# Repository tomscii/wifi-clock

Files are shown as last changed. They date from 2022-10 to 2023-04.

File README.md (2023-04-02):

## NTP-synced clock and SNMP sensors over WiFi with Raspberry Pico W

(https://tomscii.sig7.se/images/wifi-clock/wifi-clock.jpg)

Details: https://tomscii.sig7.se/wifi-clock

### Project organisation

- `doc` - documentation, design notes
- `hw` - hardware design (KiCAD)
- `pico_w` - software (Pico W)

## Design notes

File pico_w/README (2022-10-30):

To build:

mkdir build && cd build
cmake -DPICO_BOARD=pico_w -DWIFI_SSID="Your Network" -DWIFI_PASSWORD="Your Password" ..
make

To upload to RPi Pico W board
(connected via USB, powered up with BOOTSEL pressed):

sudo mount /dev/sda1 /mnt/pico
sudo cp wifi_clock.uf2 /mnt/pico/
sync && sudo umount /mnt/pico

To connect using hardware UART
(PicoW pin 1 = UART0_TX, pin 2 = UART0_RX, pin 3 = GND):
minicom -D /dev/ttyUSB0 -b 115200

To connect using USB CDC:
minicom -D /dev/ttyACM0 -b 115200

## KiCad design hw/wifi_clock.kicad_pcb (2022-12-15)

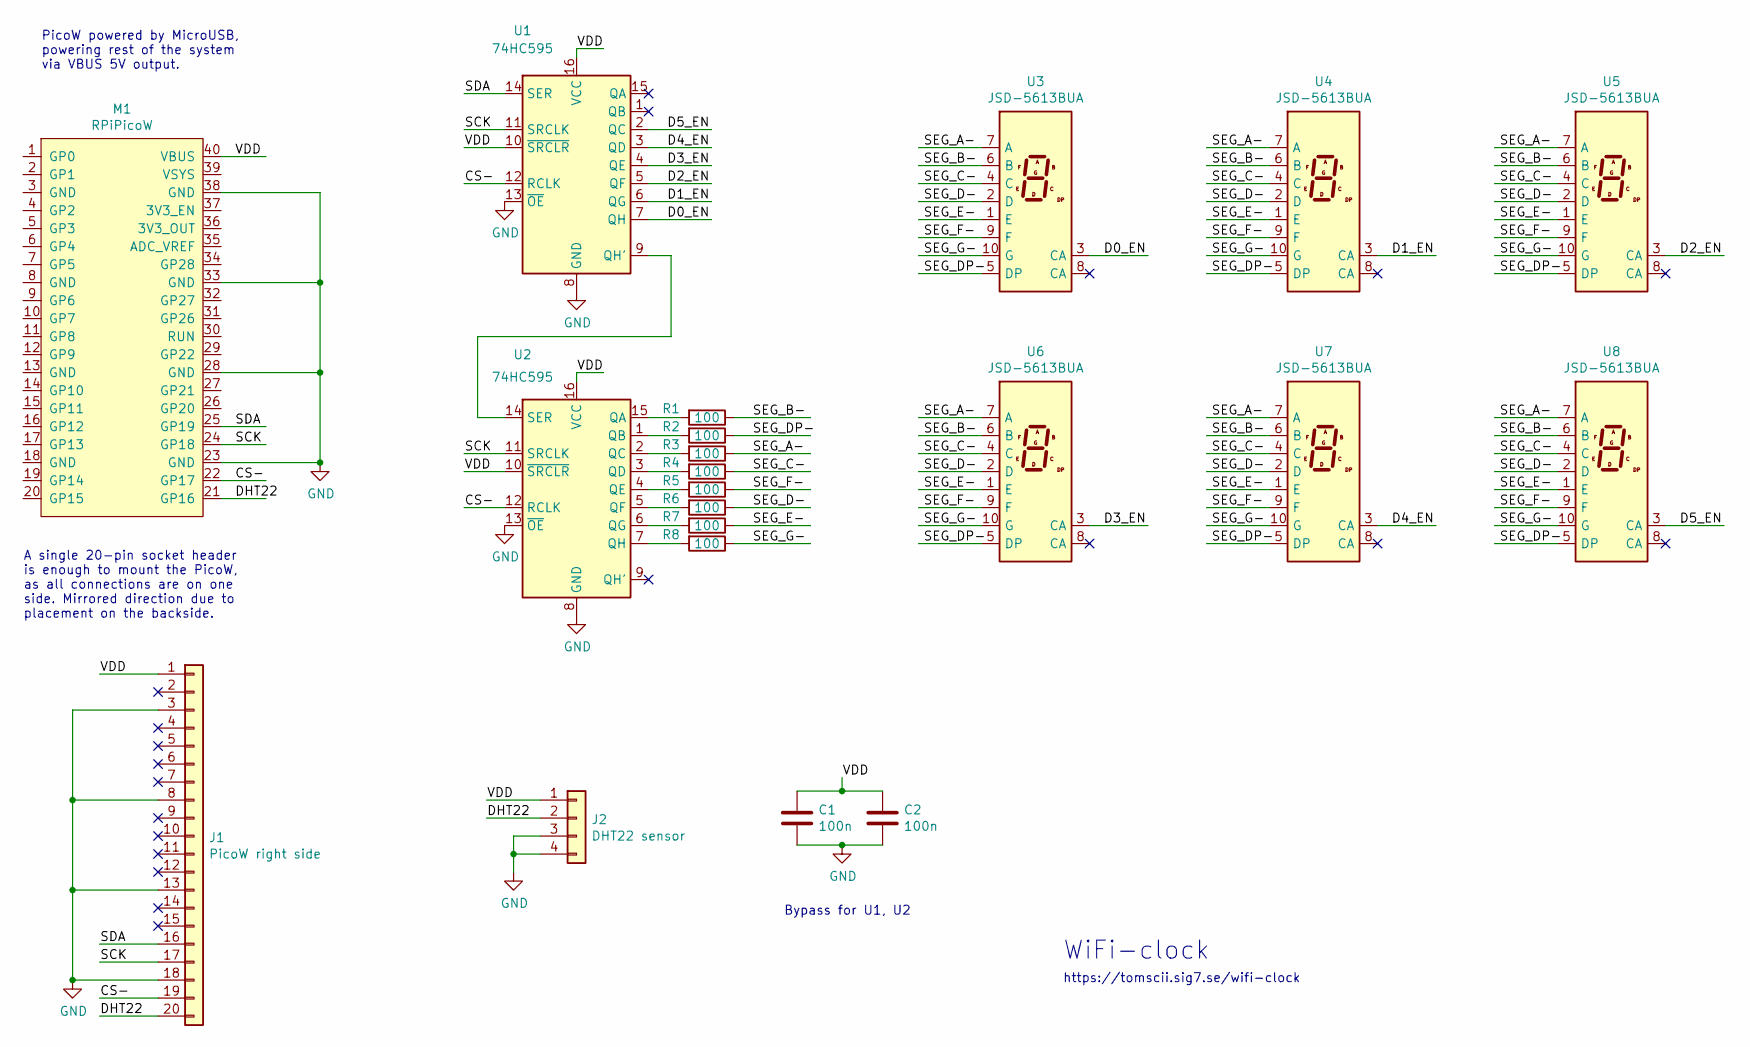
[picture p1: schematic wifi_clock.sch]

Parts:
C1, C2: 100n; C_Rect_L7.2mm_W2.5mm_P5.00mm_FKS2_FKP2_MKS2_MKP2
J1: PicoW right side; PinSocket_1x20_P2.54mm_Vertical
J2: DHT22 sensor; PinSocket_1x04_P2.54mm_Vertical
M1: RPiPicoW
R1, R2, R3, R4, R5, R6, R7, R8: 100; R_Axial_DIN0204_L3.6mm_D1.6mm_P7.62mm_Horizontal
U1, U2: 74HC595; DIP-16_W7.62mm
U3, U4, U5, U6, U7, U8: JSD-5613BUA; 7SegmentLED_LTS6760_LTS6780

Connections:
/CS-: J1.19, M1.22 (GP17), U1.12 (RCLK), U2.12 (RCLK)
/D0_EN: U1.7 (QH), U3.3 (CA)
/D1_EN: U1.6 (QG), U4.3 (CA)
/D2_EN: U1.5 (QF), U5.3 (CA)
/D3_EN: U1.4 (QE), U6.3 (CA)
/D4_EN: U1.3 (QD), U7.3 (CA)
/D5_EN: U1.2 (QC), U8.3 (CA)
/DHT22: J1.20, J2.2, M1.21 (GP16)
/SCK: J1.17, M1.24 (GP18), U1.11 (SRCLK), U2.11 (SRCLK)
/SDA: J1.16, M1.25 (GP19), U1.14 (SER)
/SEG_A-: R3.1, U3.7 (A), U4.7 (A), U5.7 (A), U6.7 (A), U7.7 (A), U8.7 (A)
/SEG_B-: R1.1, U3.6 (B), U4.6 (B), U5.6 (B), U6.6 (B), U7.6 (B), U8.6 (B)
/SEG_C-: R4.1, U3.4 (C), U4.4 (C), U5.4 (C), U6.4 (C), U7.4 (C), U8.4 (C)
/SEG_D-: R6.1, U3.2 (D), U4.2 (D), U5.2 (D), U6.2 (D), U7.2 (D), U8.2 (D)
/SEG_DP-: R2.1, U3.5 (DP), U4.5 (DP), U5.5 (DP), U6.5 (DP), U7.5 (DP), U8.5 (DP)
/SEG_E-: R7.1, U3.1 (E), U4.1 (E), U5.1 (E), U6.1 (E), U7.1 (E), U8.1 (E)
/SEG_F-: R5.1, U3.9 (F), U4.9 (F), U5.9 (F), U6.9 (F), U7.9 (F), U8.9 (F)
/SEG_G-: R8.1, U3.10 (G), U4.10 (G), U5.10 (G), U6.10 (G), U7.10 (G), U8.10 (G)
/VDD: C1.1, C2.1, J1.1, J2.1, M1.40 (VBUS), U1.10 (~SRCLR), U1.16 (VCC), U2.10 (~SRCLR), U2.16 (VCC)
GND: C1.2, C2.2, J1.3, J1.8, J1.13, J1.18, J2.3, J2.4, M1.23 (GND), M1.28 (GND), M1.33 (GND), M1.38 (GND), U1.8 (GND), U1.13 (~OE), U2.8 (GND), U2.13 (~OE)
unnamed: R1.2, U2.15 (QA)
unnamed: R2.2, U2.1 (QB)
unnamed: R3.2, U2.2 (QC)
unnamed: R4.2, U2.3 (QD)
unnamed: R5.2, U2.4 (QE)
unnamed: R6.2, U2.5 (QF)
unnamed: R7.2, U2.6 (QG)
unnamed: R8.2, U2.7 (QH)
unnamed: U1.9 (QH'), U2.14 (SER)

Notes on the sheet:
PicoW powered by MicroUSB, powering rest of the system via VBUS 5V output.
A single 20-pin socket header is enough to mount the PicoW, as all connections are on one side. Mirrored direction due to placement on the backside.
WiFi-clock
https://tomscii.sig7.se/wifi-clock
Bypass for U1, U2

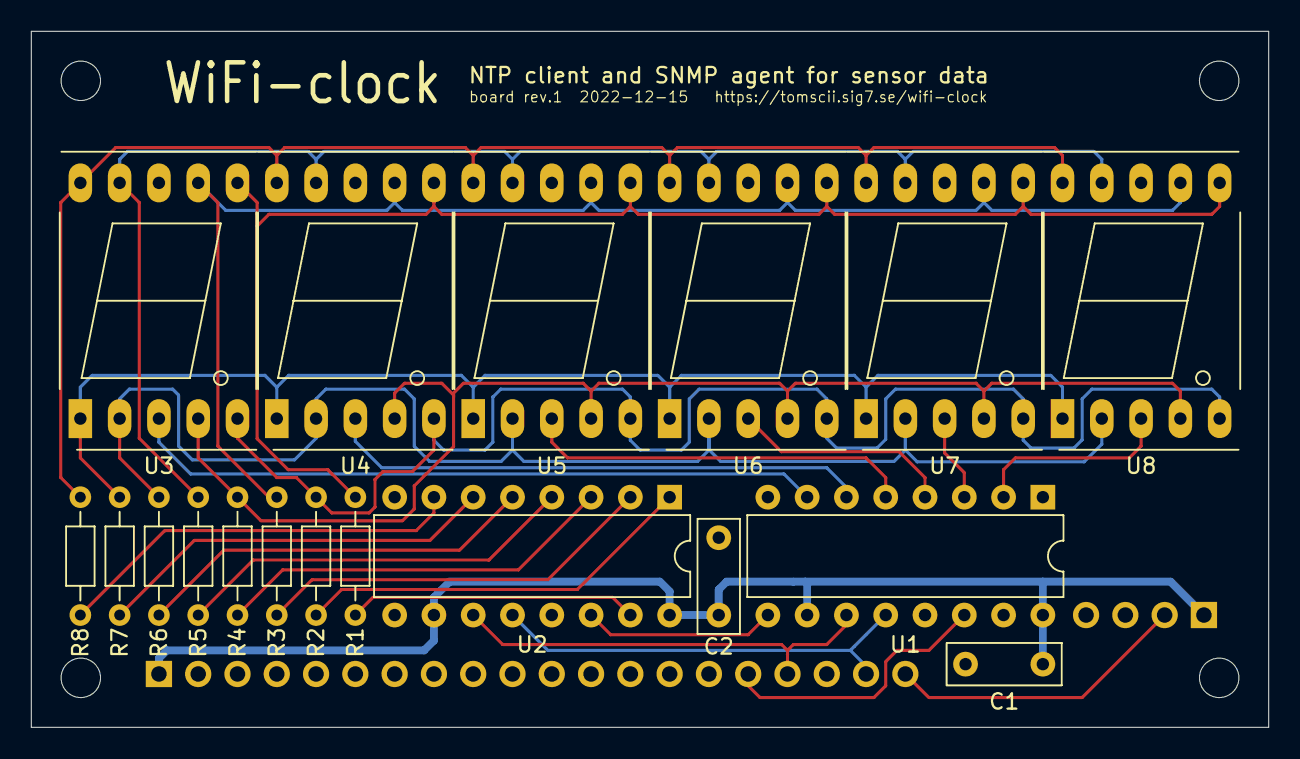
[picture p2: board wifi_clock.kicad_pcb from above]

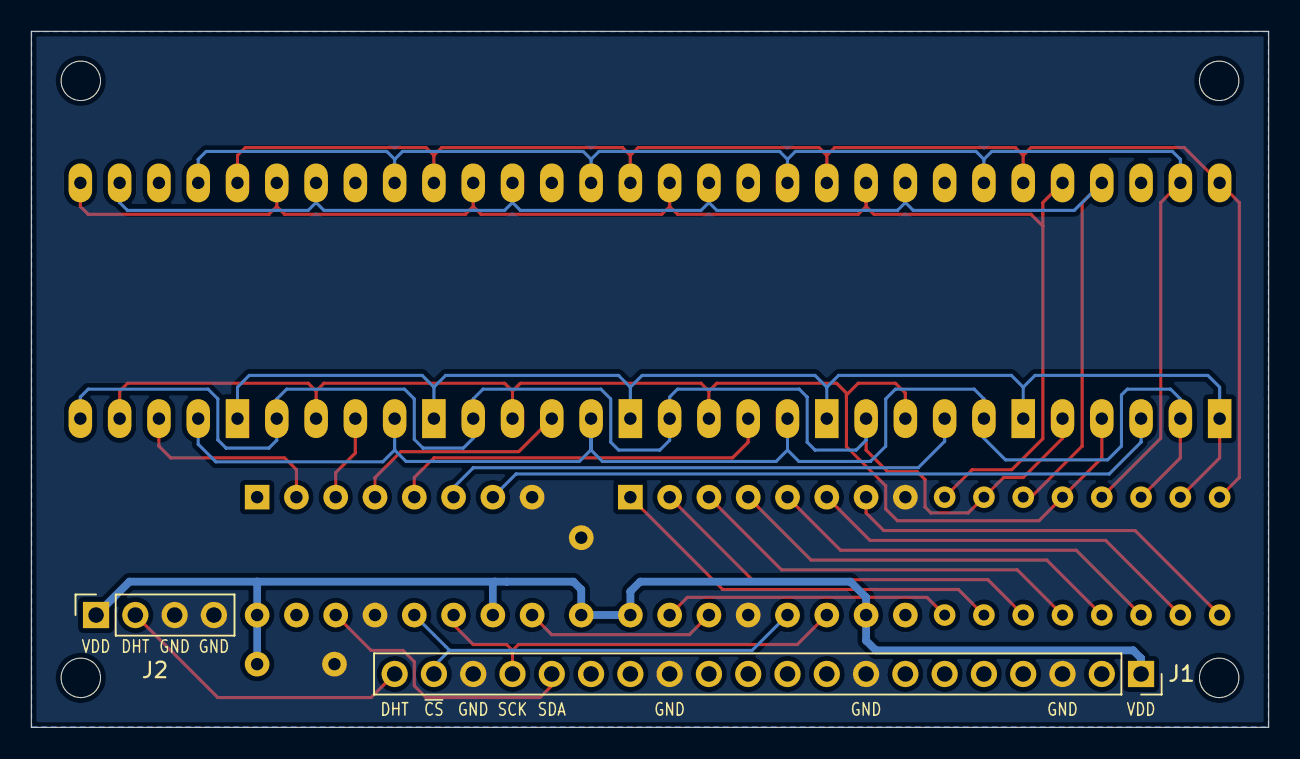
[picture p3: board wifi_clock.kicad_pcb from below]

Board: 2 copper layers, 80.0 x 45.0 mm, 20 parts (2 on the bottom side), 29 nets.

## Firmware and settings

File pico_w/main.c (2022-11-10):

#include "dht.h"
#include "display.h"
#include "ntp.h"
#include "snmp.h"
#include "wifi.h"

#include "pico/stdlib.h"
#include "pico/cyw43_arch.h"
#include "pico/util/datetime.h"

#include "hardware/rtc.h"

#include <stdio.h>
#include <string.h>
#include <time.h>

int
main ()
{
   stdio_init_all ();
   printf ("\n\nWiFi-clock\n");

   display_init ();

   rtc_init ();
   {
      datetime_t t =
         {
            .year = 2020, .month = 1, .day = 1, .dotw = 3,
            .hour = 0, .min = 0, .sec = 0
         };
      rtc_set_datetime (&t);
   }

   wifi_init ();

   ntp_t *ntp_state = ntp_init ();
   if (!ntp_state)
      return -1;

   snmp_t *snmp_state = snmp_init ();
   if (!snmp_state)
      return -1;

   dht_t *dht_state = dht_init ();
   if (!dht_state)
      return -1;

   while (1)
   {
      wifi_on_tick ();

      ntp_on_tick (ntp_state);
      dht_on_tick (dht_state);
      display_on_tick ();

      sleep_ms (20);
   }

   free (dht_state);
   free (snmp_state);
   free (ntp_state);
   cyw43_arch_deinit();
}

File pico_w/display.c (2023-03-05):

#include "display.h"

#include "hardware/rtc.h"
#include "hardware/spi.h"

static uint8_t digit = 0;
static uint8_t display [N_DIGITS] = { 0x00, 0x00, 0x00, 0x00, 0x00, 0x00 };
static repeating_timer_t rt_display_update;

static uint8_t brightness_percent = 100;

static uint8_t
seg7_encode (char c)
{
   // Drive is active low, so list dark segments for each character:
   switch (c)
   {
   case ' ': return SEG_A | SEG_B | SEG_C | SEG_D | SEG_E | SEG_F | SEG_G |
                    SEG_DP;
   case '0': return SEG_G | SEG_DP;
   case '1': return SEG_A | SEG_D | SEG_E | SEG_F | SEG_G | SEG_DP;
   case '2': return SEG_C | SEG_F | SEG_DP;
   case '3': return SEG_E | SEG_F | SEG_DP;
   case '4': return SEG_A | SEG_D | SEG_E | SEG_DP;
   case '5': return SEG_B | SEG_E | SEG_DP;
   case '6': return SEG_B | SEG_DP;
   case '7': return SEG_D | SEG_E | SEG_F | SEG_G | SEG_DP;
   case '8': return SEG_DP;
   case '9': return SEG_E | SEG_DP;
   default: return 0;
   }
}

void
display_init ()
{
   spi_init (SPI_ID, SPI_BAUDRATE);
   spi_set_format (SPI_ID, 16, SPI_CPOL_0, SPI_CPHA_0, SPI_MSB_FIRST);
   gpio_set_function (PICO_DEFAULT_SPI_SCK_PIN, GPIO_FUNC_SPI);
   gpio_set_function (PICO_DEFAULT_SPI_TX_PIN, GPIO_FUNC_SPI);
   gpio_set_function (PICO_DEFAULT_SPI_CSN_PIN, GPIO_FUNC_SPI);

   add_repeating_timer_ms (-2, update_display, NULL, &rt_display_update);
}

void
display_set_brightness (uint8_t _brightness_percent)
{
   brightness_percent = _brightness_percent;
}

void
display_on_tick ()
{
   datetime_t t;

   rtc_get_datetime (&t);

   if (t.hour < 10)
      display [0] = seg7_encode (' ');
   else
      display [0] = seg7_encode ((t.hour / 10) + '0');
   display [1] = seg7_encode ((t.hour % 10) + '0');
   display [2] = seg7_encode ((t.min / 10) + '0');
   display [3] = seg7_encode ((t.min % 10) + '0');
   display [4] = seg7_encode ((t.sec / 10) + '0');
   display [5] = seg7_encode ((t.sec % 10) + '0');

   display [1] &= ~SEG_DP;
   display [3] &= ~SEG_DP;

   uint8_t brightness = 100;
   if (t.hour < 7 || t.hour > 20)
      brightness = 2;
   else if (t.hour > 19)
      brightness = 10;
   display_set_brightness (brightness);
}

int64_t
display_off_cb (alarm_id_t id, void *user_data)
{
   uint16_t w = 0;
   spi_write16_blocking (SPI_ID, &w, 1);
   return 0;
}

bool
update_display (repeating_timer_t *rt)
{
   // Digit select is active high (common anode),
   // the lowest two digits are not connected.
   // N.B.: digit order is reversed (d.[0] is leftmost,
   // i.e., highest value) for the sake of PCB wiring!
   uint8_t v = 128 >> digit;
   // MSB gets shifted out first (driving SEG_G);
   // LSB is the lowermost unconnected digit-driving bit.
   uint16_t w = (display [digit] << 8) | v;

   // This takes 1us, as we run SPI at 16 MHz:
   spi_write16_blocking (SPI_ID, &w, 1);

   if (++digit == N_DIGITS)
      digit = 0;

   // If the brightness setting is less than 100,
   // add an alarm with a callback to blank the display
   // at a time proportional to the brightness.
   if (brightness_percent < 100)
   {
      // (brightness == 100 --> full cycle time == 2000 us)
      uint64_t display_on_us = 20 * brightness_percent;
      add_alarm_in_us (display_on_us, display_off_cb, NULL, true);
   }

   return true;
}

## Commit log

2022-10-30 Initial commit (initial HW design, SW PoC)
    [wifi_clock.kicad_pcb, wifi_clock.sch]
2022-11-10 A primitive SNMP agent
    [snmp_dump.txt]
2022-11-11 Allow SNMP request id between 0 and 4 bytes
    [snmp_dump.txt]
2022-11-11 Serve the Entity-sensor-MIB with temperature and humidity values
2022-12-15 First prototype PCB sent to AISLER manufacturing on 2022-12-15
    [wifi_clock.kicad_pcb]
2022-12-29 Fix digits ordering (final version built as prototype)
    [display.c]
2023-03-05 DHT: Fix conv of neg temps; adjust bit threshold; print raw data on failed reads
    [dht.c]
